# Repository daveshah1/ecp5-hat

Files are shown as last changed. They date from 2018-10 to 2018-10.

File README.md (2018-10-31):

# ecp5-hat

This board adds 64MB of SDRAM, 4-bit RGB+bright VGA output and a USB host connector to the Lattice [ECP5 Versa](http://www.latticesemi.com/Products/DevelopmentBoardsAndKits/ECP5VersaDevelopmentKit.aspx)
and [ECP5 Evaluation Board](http://www.latticesemi.com/en/Products/DevelopmentBoardsAndKits/ECP5EvaluationBoard)

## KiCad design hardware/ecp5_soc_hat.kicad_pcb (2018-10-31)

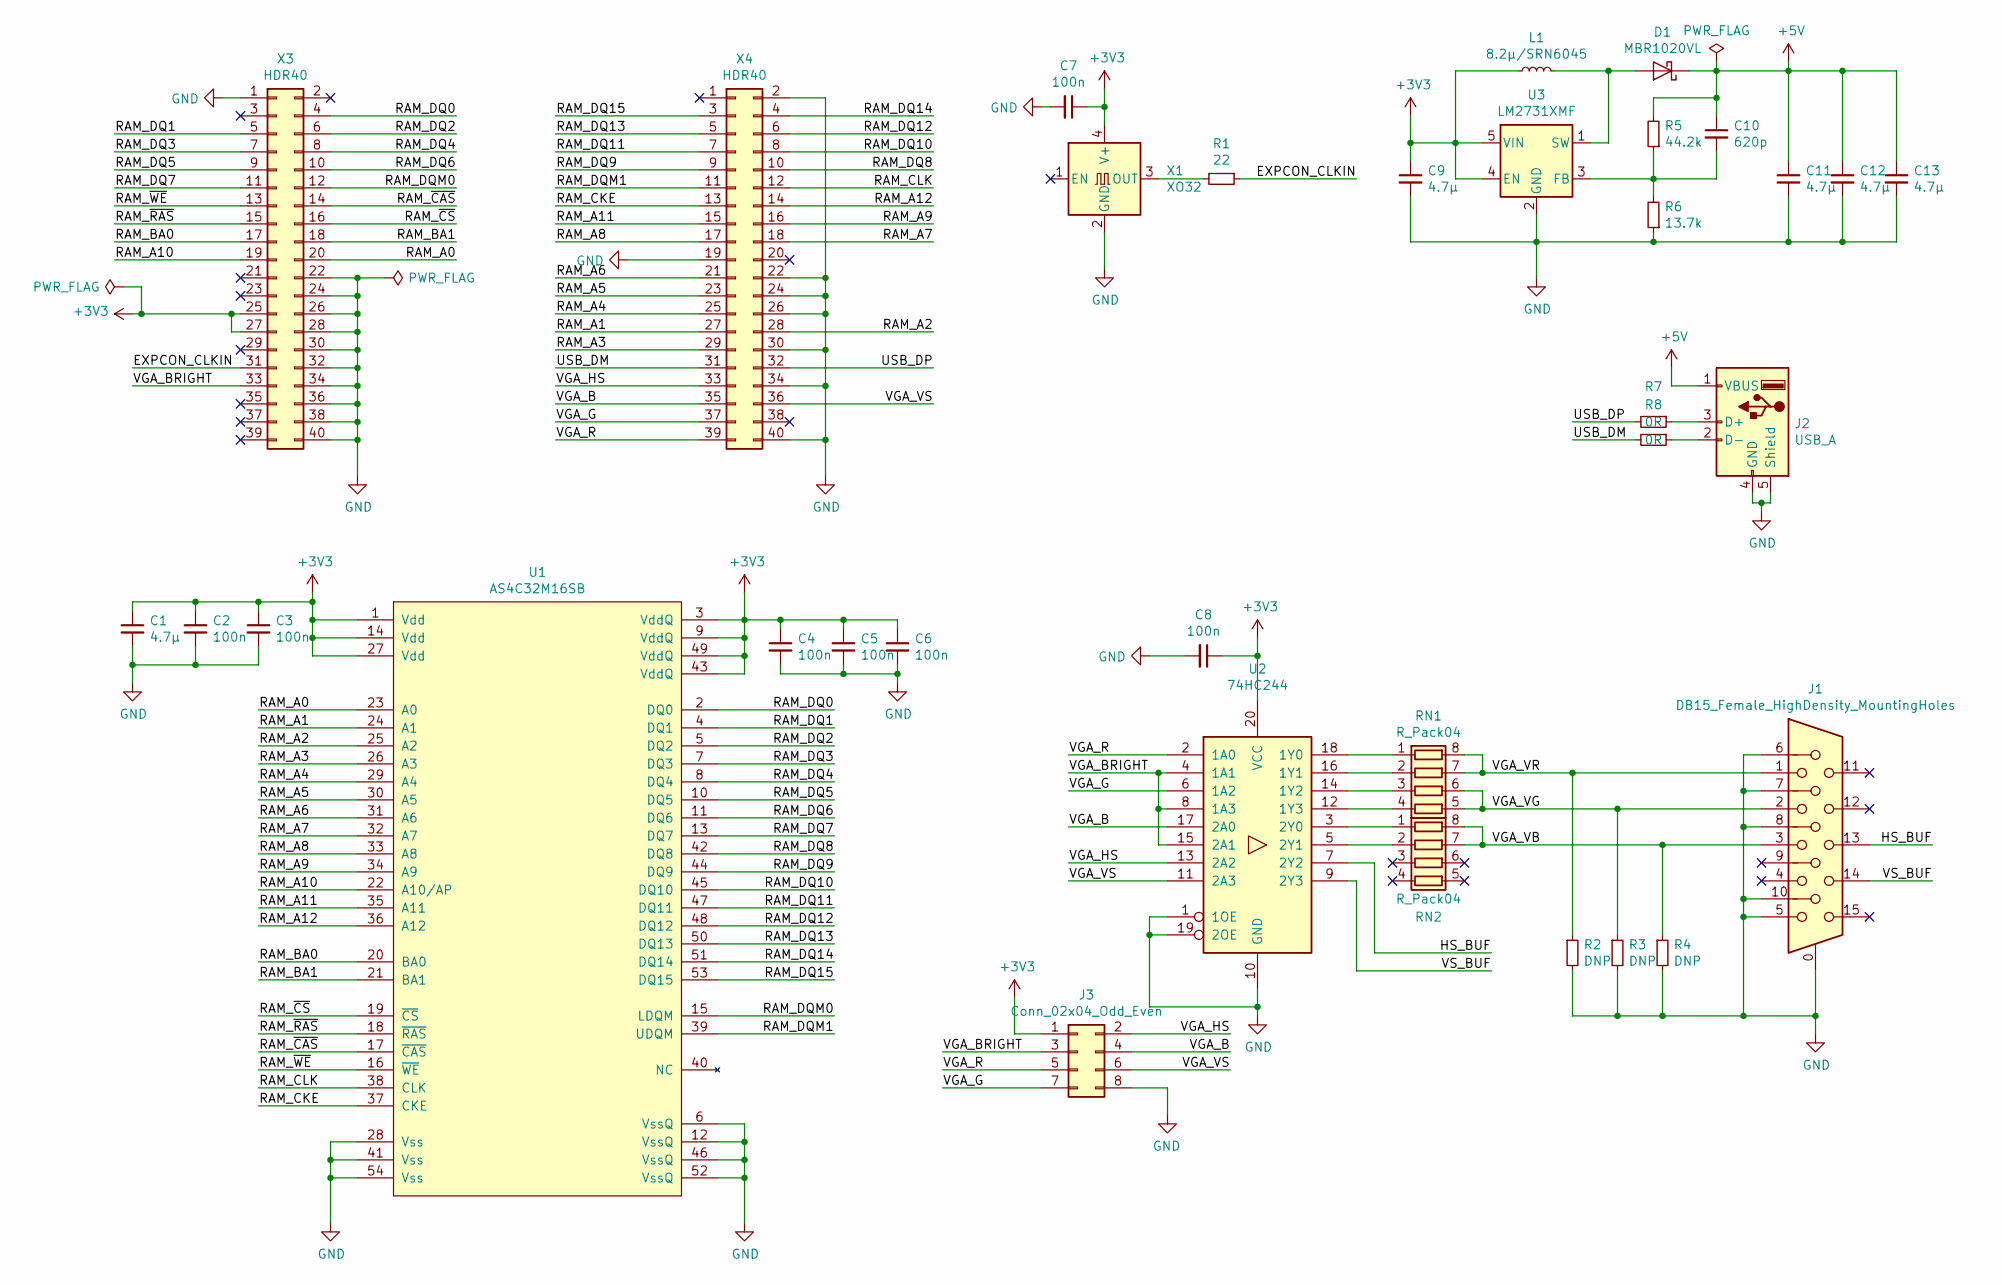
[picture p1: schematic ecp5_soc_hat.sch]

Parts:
C1, C9, C11, C12, C13: 4.7µ; C_0805_2012Metric_Pad1.15x1.40mm_HandSolder
C2, C3, C4, C5, C6, C7, C8: 100n; C_0402_1005Metric
C10: 620p; C_0402_1005Metric
D1: MBR1020VL; D_SOD-123F
J1: DB15_Female_HighDensity_MountingHoles; DSUB-15-HD_Female_Horizontal_P2.29x1.98mm_EdgePinOffset3.03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
J2: USB_A; 292303-7
J3: Conn_02x04_Odd_Even; PinHeader_2x04_P2.54mm_Vertical
L1: 8.2µ/SRN6045; SRN6045
R1: 22; R_0603_1608Metric_Pad1.05x0.95mm_HandSolder
R2, R3, R4: DNP; R_0603_1608Metric_Pad1.05x0.95mm_HandSolder
R5: 44.2k; R_0603_1608Metric_Pad1.05x0.95mm_HandSolder
R6: 13.7k; R_0603_1608Metric_Pad1.05x0.95mm_HandSolder
R7, R8: 0R; R_0603_1608Metric_Pad1.05x0.95mm_HandSolder
RN1, RN2: R_Pack04; R_Array_Convex_4x0402
U1: AS4C32M16SB; TSOP-II-54_22.2x10.16mm_P0.8mm
U2: 74HC244; SO-20_12.8x7.5mm_P1.27mm
U3: LM2731XMF; SOT-23-5
X1: XO32; Oscillator_SMD_EuroQuartz_XO32-4Pin_3.2x2.5mm
X3, X4: HDR40; PinSocket_2x20_P2.54mm_Vertical

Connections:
+3V3: C1.1, C2.1, C3.1, C4.1, C5.1, C6.1, C7.1, C8.1, C9.1, J3.1, L1.1, U1.1 (Vdd), U1.3 (VddQ), U1.9 (VddQ), U1.14 (Vdd), U1.27 (Vdd), U1.43 (VddQ), U1.49 (VddQ), U2.20 (VCC), U3.4 (EN), U3.5 (VIN), X1.4 (V+), X3.25, X3.27
+5V: C10.1, C11.1, C12.1, C13.1, D1.1 (K), J2.1 (VBUS), R5.2
/EXPCON_CLKIN: R1.1, X3.31
/EXPCON_OSC: X3.29
/HS_BUF: J1.13, U2.7 (2Y2)
/RAM_A0: U1.23 (A0), X3.20
/RAM_A1: U1.24 (A1), X4.27
/RAM_A2: U1.25 (A2), X4.28
/RAM_A3: U1.26 (A3), X4.29
/RAM_A4: U1.29 (A4), X4.25
/RAM_A5: U1.30 (A5), X4.23
/RAM_A6: U1.31 (A6), X4.21
/RAM_A7: U1.32 (A7), X4.18
/RAM_A8: U1.33 (A8), X4.17
/RAM_A9: U1.34 (A9), X4.16
/RAM_A10: U1.22 (A10/AP), X3.19
/RAM_A11: U1.35 (A11), X4.15
/RAM_A12: U1.36 (A12), X4.14
/RAM_BA0: U1.20 (BA0), X3.17
/RAM_BA1: U1.21 (BA1), X3.18
/RAM_CKE: U1.37 (CKE), X4.13
/RAM_CLK: U1.38 (CLK), X4.12
/RAM_DQ0: U1.2 (DQ0), X3.4
/RAM_DQ1: U1.4 (DQ1), X3.5
/RAM_DQ2: U1.5 (DQ2), X3.6
/RAM_DQ3: U1.7 (DQ3), X3.7
/RAM_DQ4: U1.8 (DQ4), X3.8
/RAM_DQ5: U1.10 (DQ5), X3.9
/RAM_DQ6: U1.11 (DQ6), X3.10
/RAM_DQ7: U1.13 (DQ7), X3.11
/RAM_DQ8: U1.42 (DQ8), X4.10
/RAM_DQ9: U1.44 (DQ9), X4.9
/RAM_DQ10: U1.45 (DQ10), X4.8
/RAM_DQ11: U1.47 (DQ11), X4.7
/RAM_DQ12: U1.48 (DQ12), X4.6
/RAM_DQ13: U1.50 (DQ13), X4.5
/RAM_DQ14: U1.51 (DQ14), X4.4
/RAM_DQ15: U1.53 (DQ15), X4.3
/RAM_DQM0: U1.15 (LDQM), X3.12
/RAM_DQM1: U1.39 (UDQM), X4.11
/RAM_~CAS: U1.17 (~CAS), X3.14
/RAM_~CS: U1.19 (~CS), X3.16
/RAM_~RAS: U1.18 (~RAS), X3.15
/RAM_~WE: U1.16 (~WE), X3.13
/USB_DM: R8.2, X4.31
/USB_DP: R7.2, X4.32
/VGA_B: J3.4, U2.17 (2A0), X4.35
/VGA_BRIGHT: J3.3, U2.4 (1A1), U2.8 (1A3), U2.15 (2A1), X3.33
/VGA_G: J3.7, U2.6 (1A2), X4.37
/VGA_HS: J3.2, U2.13 (2A2), X4.33
/VGA_R: J3.5, U2.2 (1A0), X4.39
/VGA_VB: J1.3, R4.1, RN2.7 (R2.2), RN2.8 (R1.2)
/VGA_VG: J1.2, R3.1, RN1.5 (R4.2), RN1.6 (R3.2)
/VGA_VR: J1.1, R2.1, RN1.7 (R2.2), RN1.8 (R1.2)
/VGA_VS: J3.6, U2.11 (2A3), X4.36
/VS_BUF: J1.14, U2.9 (2Y3)
GND: C1.2, C2.2, C3.2, C4.2, C5.2, C6.2, C7.2, C8.2, C9.2, C11.2, C12.2, C13.2, J1.0, J1.5, J1.6, J1.7, J1.8, J1.10, J2.4 (GND), J2.5 (Shield), J3.8, R2.2, R3.2, R4.2, R6.1, U1.6 (VssQ), U1.12 (VssQ), U1.28 (Vss), U1.41 (Vss), U1.46 (VssQ), U1.52 (VssQ), U1.54 (Vss), U2.1 (1OE), U2.10 (GND), U2.19 (2OE), U3.2 (GND), X1.2 (GND), X3.1, X3.22, X3.24, X3.26, X3.28, X3.30, X3.32, X3.34, X3.36, X3.38, X3.40, X4.2, X4.19, X4.22, X4.24, X4.26, X4.30, X4.34, X4.40
unnamed: C10.2, R5.1, R6.2, U3.3 (FB)
unnamed: D1.2 (A), L1.2, U3.1 (SW)
unnamed: J2.2 (D-), R8.1
unnamed: J2.3 (D+), R7.1
unnamed: R1.2, X1.3 (OUT)
unnamed: RN1.1 (R1.1), U2.18 (1Y0)
unnamed: RN1.2 (R2.1), U2.16 (1Y1)
unnamed: RN1.3 (R3.1), U2.14 (1Y2)
unnamed: RN1.4 (R4.1), U2.12 (1Y3)
unnamed: RN2.1 (R1.1), U2.3 (2Y0)
unnamed: RN2.2 (R2.1), U2.5 (2Y1)

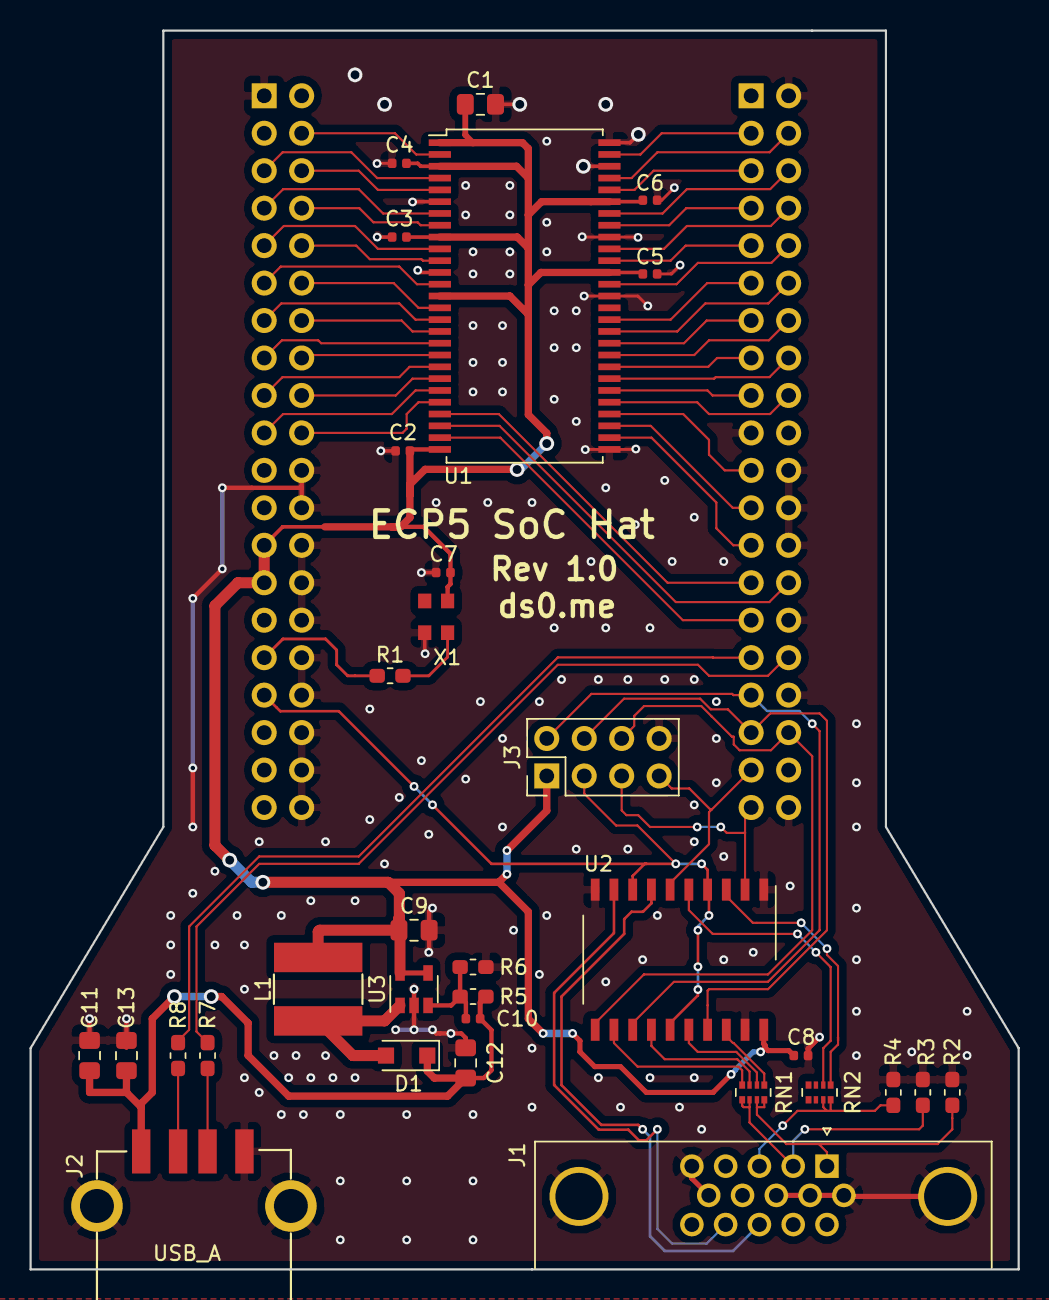
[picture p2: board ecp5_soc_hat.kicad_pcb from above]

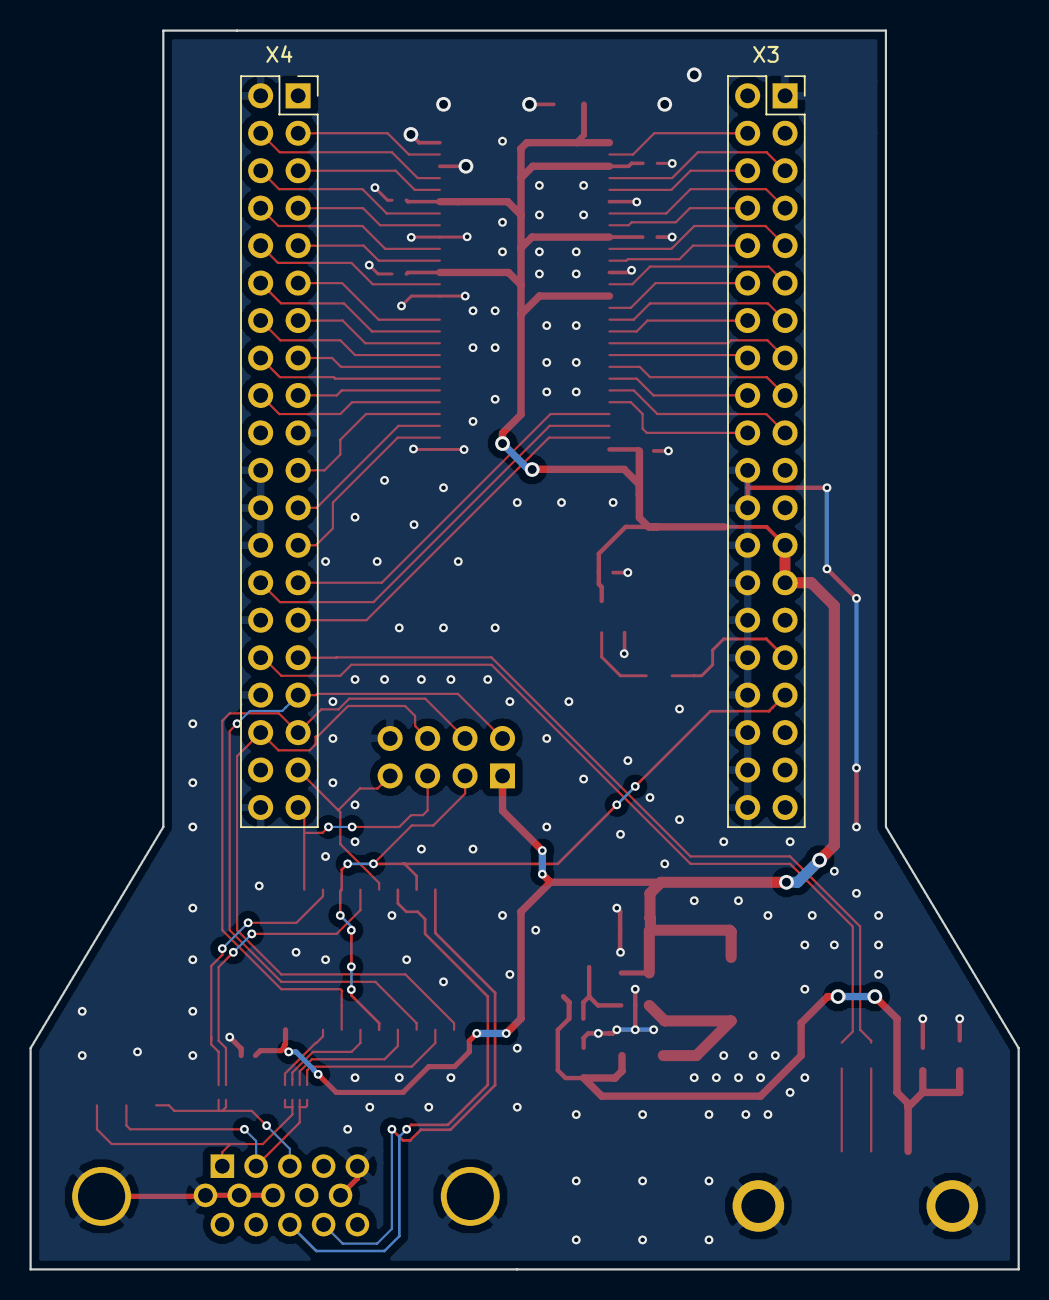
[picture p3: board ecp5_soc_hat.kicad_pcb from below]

Board: 2 copper layers, 67.0 x 84.0 mm, 34 parts (2 on the bottom side), 67 nets.

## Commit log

2018-10-20 Initial schematics
    [ecp5_soc_hat.kicad_pcb, ecp5_soc_hat.sch]
2018-10-20 Initial PCB placement
    [ecp5_soc_hat.kicad_pcb, ecp5_soc_hat.sch]
2018-10-20 PCB fully routed
    [ecp5_soc_hat.kicad_pcb, ecp5_soc_hat.sch]
2018-10-20 Tidy up board
    [ecp5_soc_hat.kicad_pcb]
2018-10-31 Production PCBs rev1.0
    [ecp5_soc_hat-B.Cu.gbl, ecp5_soc_hat-B.Mask.gbs, ecp5_soc_hat-B.SilkS.gbo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]
